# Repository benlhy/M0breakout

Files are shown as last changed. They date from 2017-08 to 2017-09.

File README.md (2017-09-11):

# M0+ breakout
M0+ Breakout Board

This breakout board combines both the Adafruit M0 Feather and the Sparkfun board. From the Adafruit board comes Lipo charging, and from the Sparkfun board comes the full breakout. The header pins for SWO programming are broken out, and a microUSB interface is provided just in case you do compile your own bootloader.

# Bootloaders
Both companies have provided tools to create their bootloaders. However do note that you'll have to use your own VID/PID for USB if you are planning to use it in your own products. The Adafruit bootloader is preferred since it is more up to date.

# Firmware references
1. https://learn.adafruit.com/compiling-m0-atsamd21-bootloader/compile
2. https://github.com/adafruit/Adafruit-Feather-M0-Basic-Proto-PCB
3. https://github.com/sparkfun/SAMD21_Dev_Breakout
4. https://github.com/sparkfun/SAMD21_Mini_Breakout

# Thanks
Adafruit and Sparkfun invests time and resources in providing open designs. This project would not have been possible without their guides. Support Adafruit and Sparkfun and open-source hardware by purchasing products from them!

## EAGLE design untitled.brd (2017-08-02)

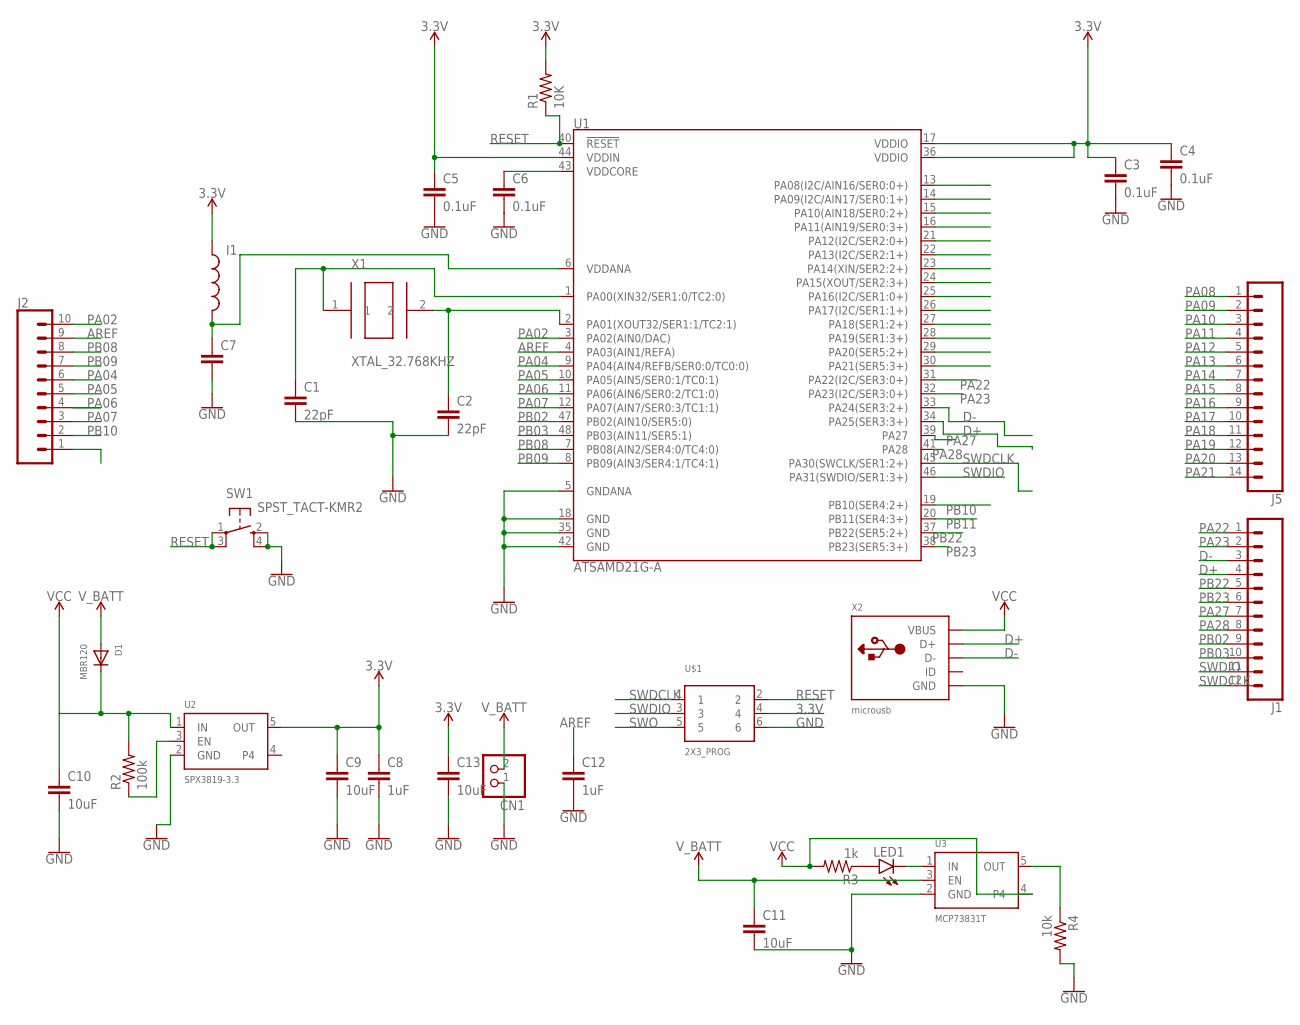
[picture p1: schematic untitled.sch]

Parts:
C1, C2: 22pF; 0805
C3, C4, C5, C6: 0.1uF; 0805
C7: CAP; 0805
C8, C12: 1uF; 0805
C9, C10, C11, C13: 10uF; 0805
CN1: JST_2PIN; JSTPH2
D1: MBR120; SOD-123
I1: IND; 0805
J1: CONN_12; 1X12
J2: CONN_10"; 1X10
J5: CONN_14; 1X14
LED1: LED0603; LED-0603
R1: 10K; 0805
R2: 100k; 0805
R3: 1k; 0805
R4: 10k; 0805
SW1: SPST_TACT-KMR2; KMR2
U1: ATSAMD21G-A; TQFP-48
U2: SPX3819-3.3; SOT23-5
U3: MCP73831T; SOT23-5
U$1: 2X3_PROG; 2X3-SMD_PROG
X1: XTAL_32.768KHZ; ABS07-32.768KHZ-9-T
X2: microusb; 4UCONN_20329_V2

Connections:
3.3V: C3.1, C4.1, C5.1, C8.1, C9.1, C13.1, I1.1, R1.2, U1.17 (VDDIO), U1.36 (VDDIO), U1.44 (VDDIN), U2.5 (OUT), U$1.4
AREF: C12.1, J2.9, U1.4 (PA03(AIN1/REFA))
D+: J1.4, U1.34 (PA25(SER3:3+)), X2.D+
D-: J1.3, U1.33 (PA24(SER3:2+)), X2.D-
GND: C1.2, C2.2, C3.2, C4.2, C5.2, C6.2, C7.2, C8.2, C9.2, C10.2, C11.2, C12.2, C13.2, CN1.1, R4.2, SW1.2 (S), SW1.4 (S1), U1.5 (GNDANA), U1.18 (GND), U1.35 (GND), U1.42 (GND), U2.2 (GND), U3.2 (GND), U$1.6, X2.BASE@1 (GND), X2.BASE@2 (GND), X2.GND, X2.SPRT@1 (GND), X2.SPRT@2 (GND), X2.SPRT@3 (GND), X2.SPRT@4 (GND)
unnamed: C1.1, U1.1 (PA00(XIN32/SER1:0/TC2:0)), X1.1
unnamed: C2.1, U1.2 (PA01(XOUT32/SER1:1/TC2:1)), X1.2
unnamed: C6.1, U1.43 (VDDCORE)
unnamed: C7.1, I1.2, U1.6 (VDDANA)
unnamed: R2.1, U2.3 (EN)
unnamed: LED1.A, R3.1
unnamed: LED1.C, U3.1 (IN)
unnamed: R4.1, U3.5 (OUT)
PA02: J2.10, U1.3 (PA02(AIN0/DAC))
PA04: J2.6, U1.9 (PA04(AIN4/REFB/SER0:0/TC0:0))
PA05: J2.5, U1.10 (PA05(AIN5/SER0:1/TC0:1))
PA06: J2.4, U1.11 (PA06(AIN6/SER0:2/TC1:0))
PA07: J2.3, U1.12 (PA07(AIN7/SER0:3/TC1:1))
PA08: J5.1, U1.13 (PA08(I2C/AIN16/SER0:0+))
PA09: J5.2, U1.14 (PA09(I2C/AIN17/SER0:1+))
PA10: J5.3, U1.15 (PA10(AIN18/SER0:2+))
PA11: J5.4, U1.16 (PA11(AIN19/SER0:3+))
PA12: J5.5, U1.21 (PA12(I2C/SER2:0+))
PA13: J5.6, U1.22 (PA13(I2C/SER2:1+))
PA14: J5.7, U1.23 (PA14(XIN/SER2:2+))
PA15: J5.8, U1.24 (PA15(XOUT/SER2:3+))
PA16: J5.9, U1.25 (PA16(I2C/SER1:0+))
PA17: J5.10, U1.26 (PA17(I2C/SER1:1+))
PA18: J5.11, U1.27 (PA18(SER1:2+))
PA19: J5.12, U1.28 (PA19(SER1:3+))
PA20: J5.13, U1.29 (PA20(SER5:2+))
PA21: J5.14, U1.30 (PA21(SER5:3+))
PA22: J1.1, U1.31 (PA22(I2C/SER3:0+))
PA23: J1.2, U1.32 (PA23(I2C/SER3:0+))
PA27: J1.7, U1.39 (PA27)
PA28: J1.8, U1.41 (PA28)
PB02: J1.9, U1.47 (PB02(AIN10/SER5:0))
PB03: J1.10, U1.48 (PB03(AIN11/SER5:1))
PB08: J2.8, U1.7 (PB08(AIN2/SER4:0/TC4:0))
PB09: J2.7, U1.8 (PB09(AIN3/SER4:1/TC4:1))
PB10: J2.2, U1.19 (PB10(SER4:2+))
PB11: J2.1, U1.20 (PB11(SER4:3+))
PB22: J1.5, U1.37 (PB22(SER5:2+))
PB23: J1.6, U1.38 (PB23(SER5:3+))
RESET: R1.1, SW1.1, SW1.3 (P1), U1.40 (!RESET!), U$1.2
SWDCLK: J1.12, U1.45 (PA30(SWCLK/SER1:2+)), U$1.1
SWDIO: J1.11, U1.46 (PA31(SWDIO/SER1:3+)), U$1.3
SWO: U$1.5
VCC: C10.1, D1.C, R2.2, R3.2, U2.1 (IN), U3.4, X2.VBUS
V_BATT: C11.1, CN1.2, D1.A, U3.3 (EN)

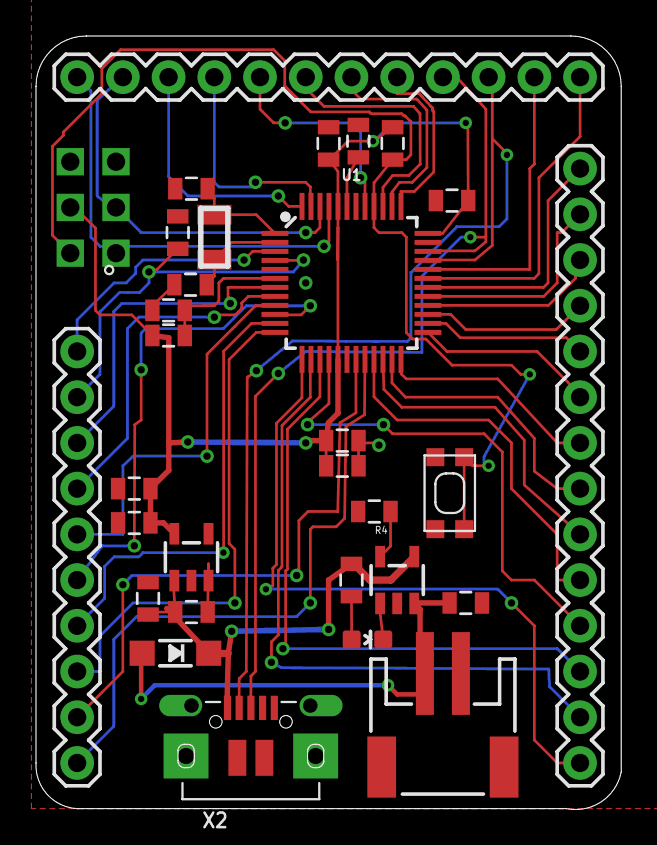
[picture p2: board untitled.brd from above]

Board: 2 copper layers, 32.5 x 43.0 mm, 31 parts (0 on the bottom side), 49 nets.

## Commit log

2017-07-10 Initial upload
    [untitled.brd, untitled.sch]
2017-08-02 update Readme and boards
    Boards updated to reduce vias and moved the reset button location
    [untitled.brd]

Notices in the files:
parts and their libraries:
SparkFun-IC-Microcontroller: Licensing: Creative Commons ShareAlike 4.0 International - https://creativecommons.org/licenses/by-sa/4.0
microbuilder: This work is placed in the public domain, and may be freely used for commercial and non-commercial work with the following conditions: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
